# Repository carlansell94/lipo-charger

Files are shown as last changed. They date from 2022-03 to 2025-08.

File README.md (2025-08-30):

LiPo battery chargers based on the Adafruit MicroLipo, with added reverse polarity protection.

Features:
* Based on a proven and tested design by Adafruit.
* Includes JST-PH and JST-ZH footprints to support a wider range of battery connectors.
* v1 supports 1x JST-PH port and 1x JST-ZH port, while v2 has 2 of each port - the second pair on the rear swapping the polarity of the connector.
* Includes an additional output port for batteries using a JST-PZ connector.
* Reverse polarity protection for the charging IC, useful if you're dealing with batteries with the wires switched around (such as a Dualshock 4 battery).
* v2 features a USB type C port for power input, and a surface-mount switch to choose between fast and slow charging modes (v1 required soldering a resistor).

Note that you MUST NOT try to use multiple ports at once, this board is only designed to charge one battery at a time.

The original Adafruit design can be found [here](https://learn.adafruit.com/adafruit-microlipo-and-minilipo-battery-chargers/downloads).

Included in this repository are the KiCAD files for both designs. If you're only interested in having them manufactured, gerbers are available under 'releases'.

## Parts Lists
v1 Parts List:
| Component |Qty| Symbol(s) |
| --- | - | --- |
| USB Micro B Port | 1 | X1 |
| MCP73831/2 SOT23 Charging IC | 1 | U1 |
| 0805 10uF Capacitor | 2 | C1,C2 |
| 0805 470Ω Resistor | 2 | R1,R2 |
| 0805 10kΩ Resistor | 1 | R3 |
| 0805 2.49kΩ Resistor | 1 | R4 |
| 0805 100kΩ Resistor | 1 | R5 |
| 0805 1MΩ Resistor | 1 | R6 |
| ZXMP3A13FTA P Channel MOSFET | 1 | Q1 |
| MMBT3904,215 BJT NPN Transistor | 1 | Q2 |
| 0805 LED (Colours Optional) | 2 | LED1,LED2 |
| JST-PH Connector | 1 | CN1 |
| JST-PZ Connector | 1 | CN2 | (Optional)
| 0805 0Ω Resistor | 1 | SJ1 | (Optional)

v2 Parts List:
| Component |Qty| Symbol(s) |
| --- | - | --- |
| 16-pin USB Type C Port | 1 | J1 |
| MCP73831/2 SOT23 Charging IC | 1 | U1 |
| 0805 10uF Capacitor | 2 | C1,C2 |
| 0805 470Ω Resistor | 2 | R1,R2 |
| 0805 10kΩ Resistor | 1 | R3 |
| 0805 2kΩ Resistor | 1 | R4 |
| 0805 100kΩ Resistor | 1 | R5 |
| 0805 1MΩ Resistor | 1 | R6 |
| 0805 5.1kΩ Resistor | 2 | R7,R8 | (Optional)
| ZXMP3A13FTA P Channel MOSFET | 1 | Q1 |
| MMBT3904,215 BJT NPN Transistor | 1 | Q2 |
| 0805 LED (Colours Optional) | 2 | LED1,LED2 |
| JST-PH Connector | 2 | CN1,CN4 |
| JST-PZ Connector | 1 | CN2,CN3 | (Optional)
| PCM12SMTR Slide Switch | 1 | SW1 | (Optional)

For more information on the v1 (micro USB) board, take a look at [my blog post](https://qubitsandbytes.co.uk/lipo-charger-with-reverse-polarity-protection/).

For more information on the v2 (USB type C) board, take a look at [this post](https://qubitsandbytes.co.uk/building-a-better-lipo-battery-charger/).

## Images
v1 KiCAD render:

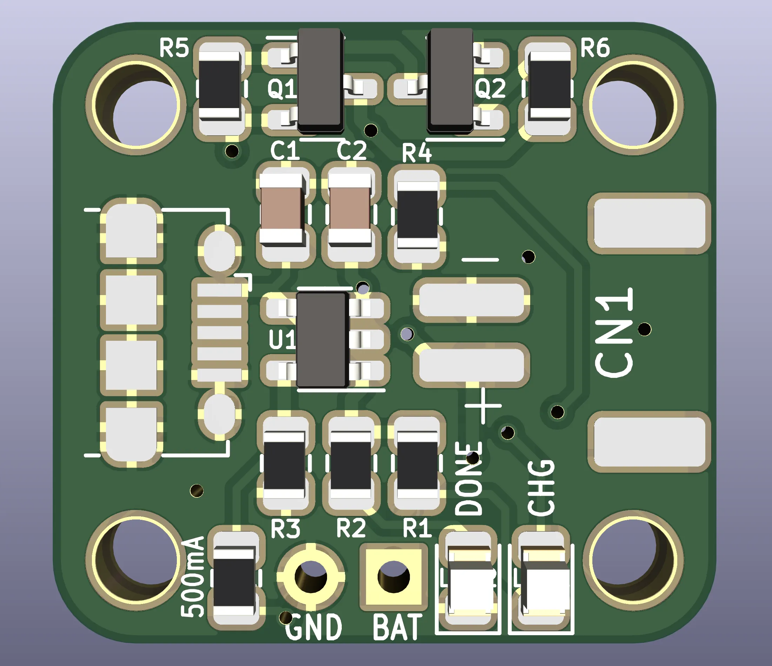
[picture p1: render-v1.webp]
v1 KiCAD render KiCAD render of the v1 board


v2 KiCAD render:

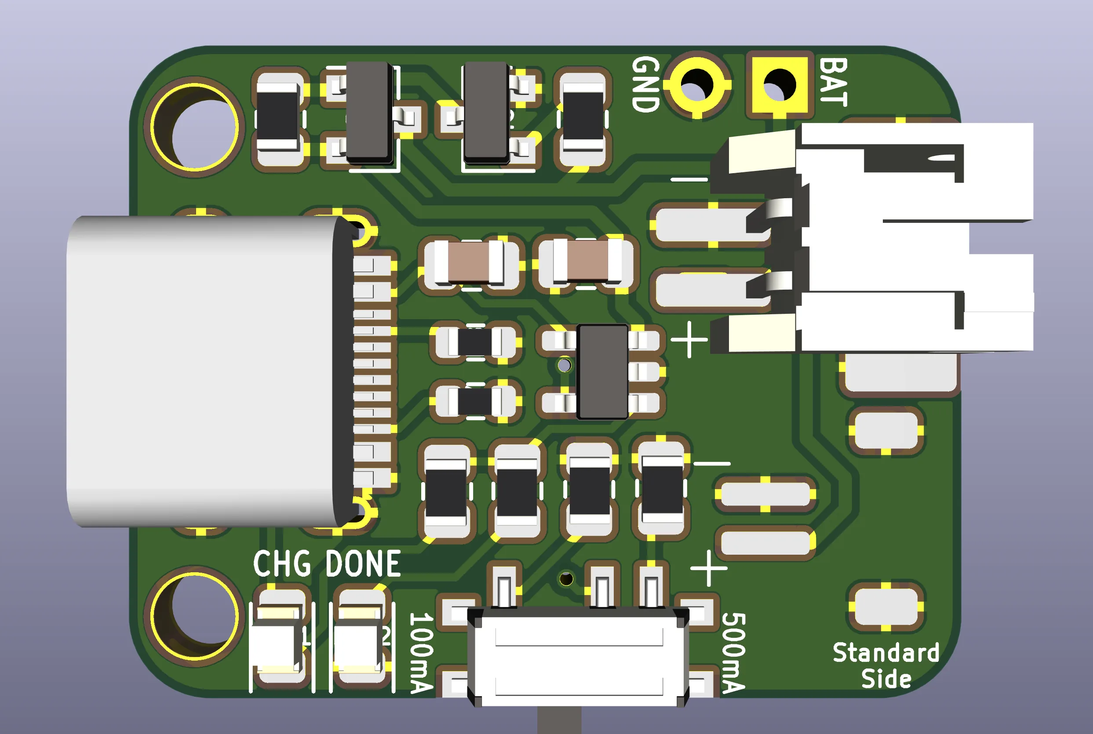
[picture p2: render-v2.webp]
v2 KiCAD render KiCAD render of the v2 board


## KiCAD
The files in this project were created using KiCAD. To open these files, make sure you're using KiCAD v9 or above.

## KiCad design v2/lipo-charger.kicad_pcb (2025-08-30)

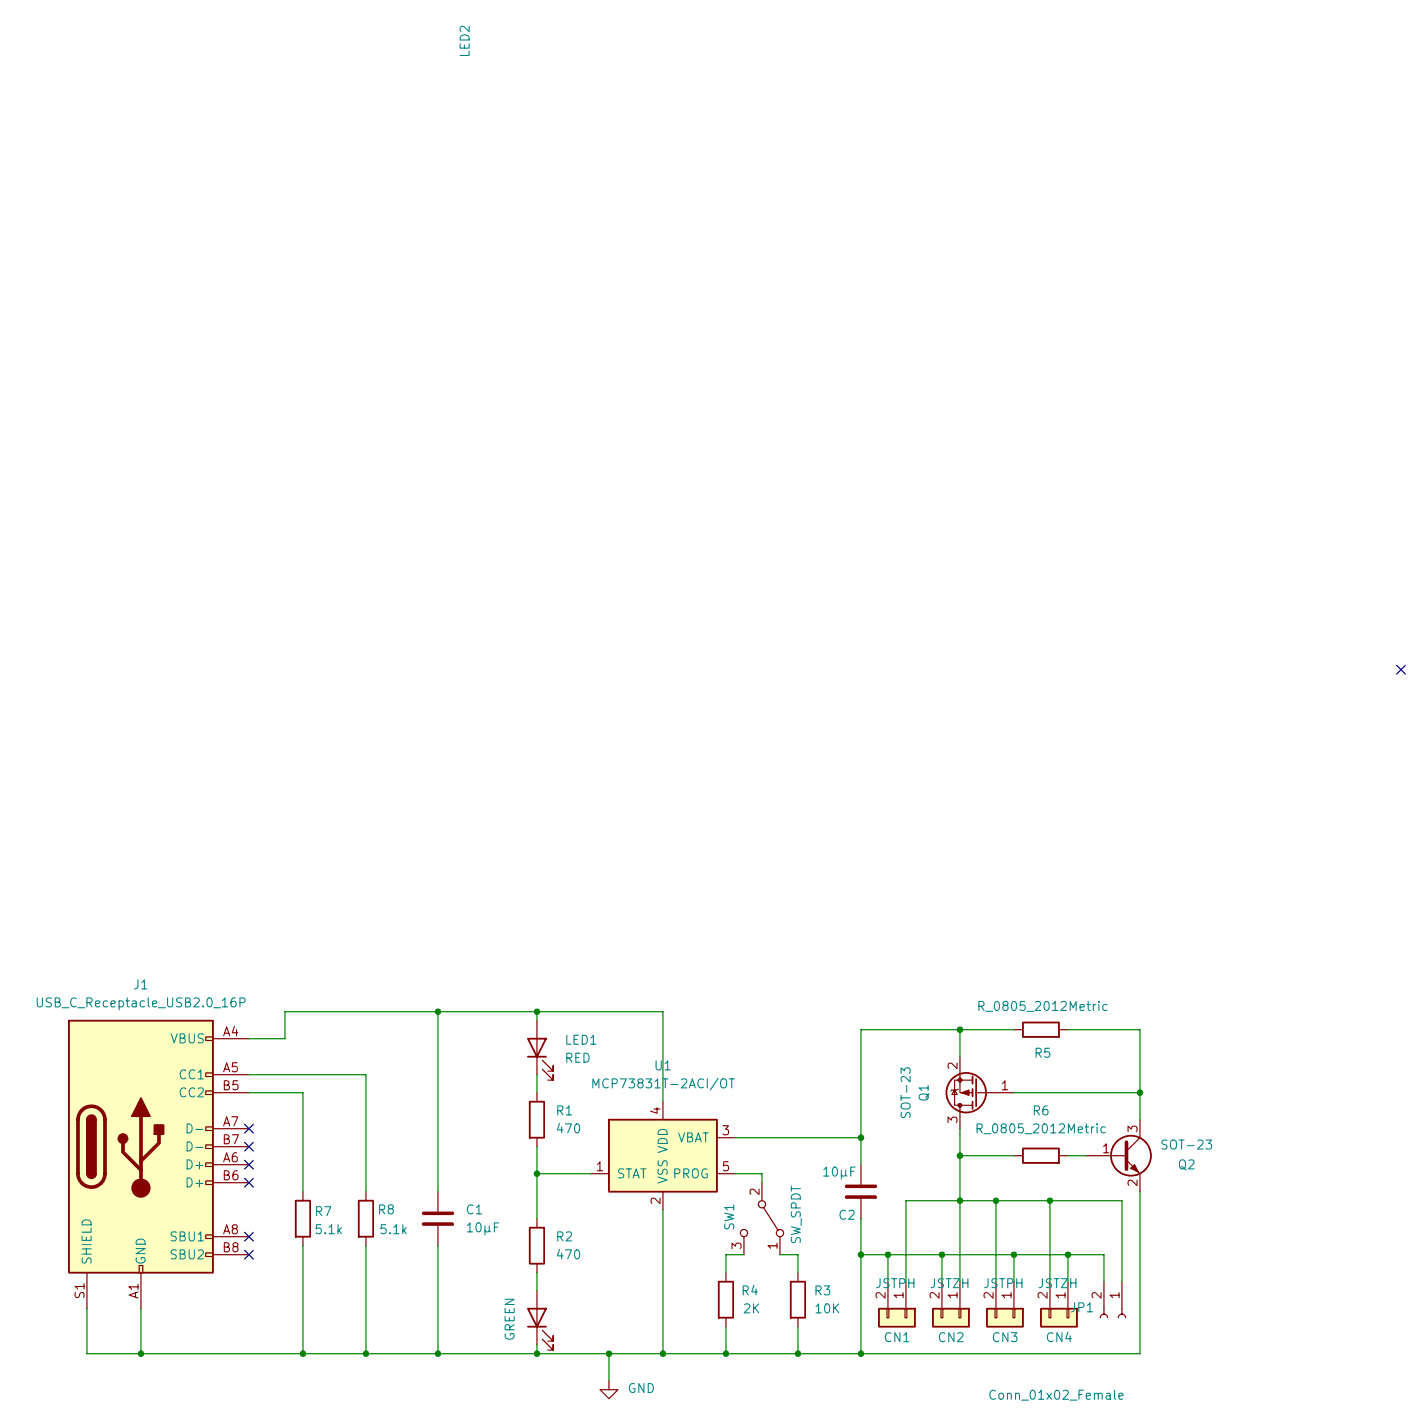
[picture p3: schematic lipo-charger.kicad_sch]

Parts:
C1, C2: 10µF; C_0805_2012Metric
CN1, CN3: JSTPH; JST_PH_S2B-PH-SM4-TB_1x02-1MP_P2.00mm_Horizontal
CN2, CN4: JSTZH; JST_ZH_S2B-ZR-SM4A-TF_1x02-1MP_P1.50mm_Horizontal
J1: USB_C_Receptacle_USB2.0_16P; USB_C_Receptacle_HRO_TYPE-C-31-M-12
JP1: Conn_01x02_Female; PinHeader_1x02_P2.54mm_Vertical
LED1: RED; LED_0805_2012Metric
LED2: GREEN; LED_0805_2012Metric
Q1, Q2: SOT-23
R1, R2: 470; R_0805_2012Metric
R3: 10K; R_0805_2012Metric
R4: 2K; R_0805_2012Metric
R5, R6: R_0805_2012Metric
R7, R8: 5.1k; R_0603_1608Metric
SW1: SW_SPDT; SW_SPDT_PCM12
U1: MCP73831T-2ACI/OT; SOT-23-5

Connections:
GND: C1.2, C2.2, CN1.2, CN1.MP, CN2.2, CN2.MP, CN3.1, CN3.MP, CN4.1, CN4.MP, J1.A1 (GND), J1.A12 (GND), J1.B1 (GND), J1.B12 (GND), J1.S1 (SHIELD), JP1.2, LED2.1 (K), Q2.2 (E), R3.2, R4.2, R7.2, R8.2, U1.2 (VSS)
unnamed: CN1.1, CN2.1, CN3.2, CN4.2, JP1.1, Q1.3 (D), R6.1
unnamed: J1.A5 (CC1), R8.1
unnamed: J1.B5 (CC2), R7.1
unnamed: C1.1, J1.A4 (VBUS), J1.A9 (VBUS), J1.B4 (VBUS), J1.B9 (VBUS), LED1.2 (A), U1.4 (VDD)
unnamed: LED1.1 (K), R1.1
unnamed: LED2.2 (A), R2.1
unnamed: Q1.1 (G), Q2.3 (C), R5.2
unnamed: C2.1, Q1.2 (S), R5.1, U1.3 (VBAT)
unnamed: Q2.1 (B), R6.2
unnamed: R3.1, SW1.1 (A)
unnamed: SW1.2 (B), U1.5 (PROG)
unnamed: R4.1, SW1.3 (C)
unnamed: R1.2, R2.2, U1.1 (STAT)

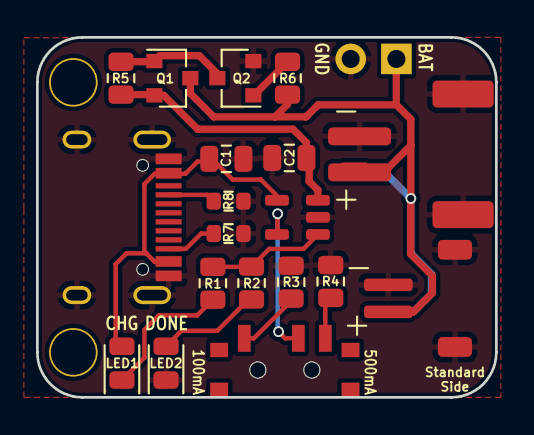
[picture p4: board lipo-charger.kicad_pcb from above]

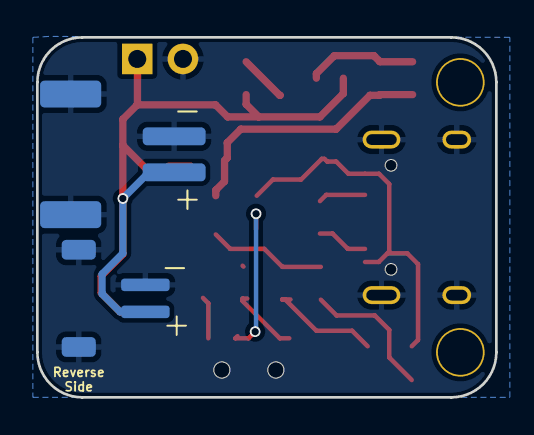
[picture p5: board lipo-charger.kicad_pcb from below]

Board: 2 copper layers, 25.5 x 20.0 mm, 24 parts (2 on the bottom side), 14 nets.

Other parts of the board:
H1, H2: MountingHole_2.5mm

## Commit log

2025-08-30 chore: Move original version into v1 folder
    [lipo-charger.kicad_pcb, lipo-charger.kicad_sch]
2025-08-30 feat: Add v2 files
    [lipo-charger.kicad_pcb, lipo-charger.kicad_sch]
